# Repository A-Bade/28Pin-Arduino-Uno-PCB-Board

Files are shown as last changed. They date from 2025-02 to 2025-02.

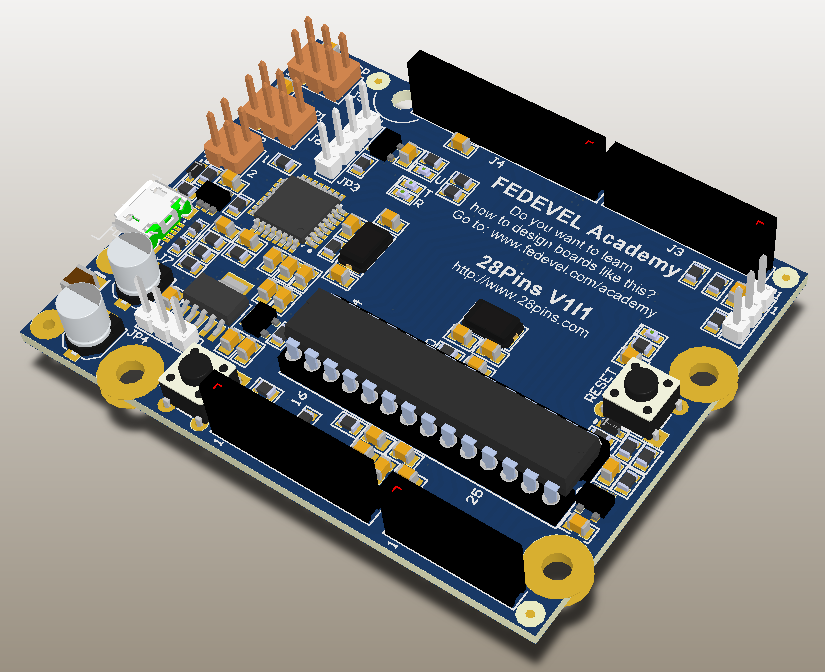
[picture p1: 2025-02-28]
!Design Documentation/Templates/Schematic/28Pins3D.png

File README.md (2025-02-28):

The repo includes:

- Mechanical Drawing (Board dimensions, holes position, ..)
- TOP and BOTTOM Assembly Drawing (Component position with Reference Designator)
- TOP and BOTTOM VIEW (shows board outline, assembly layer, TOP + BOTTOM layers)
- Bill of Materials (grouped by component type)
- Component reference BOM (each component on one line: Designator, Description, Manufacturer 1,
  Manufacturer, Part Number 1, Package / Case, Supplier 1, Supplier Part Number 1)
- Component reference BOM (as above) grouped by component type.
- Pick and Place
- TOP and BOTTOM Layer + TOP and BOTTOM Paste Gerber Files (for stencil - if panel is done in a PCB house, ask them later for the top/bottom layers and paste for the panel)
- PDF 3D Model

!!! BE AWARE !!! If you use a VARIANT were you replace a component by other component,
THIS WILL NOT BE REFLECTED IN ASSEMBLY DRAWING and component will look like not fitted.
This may be a bug in Altium 14.3. Use a TEMP Schematic to generate the ASM DRWG. SAME
FOR PICK & PLACE!!

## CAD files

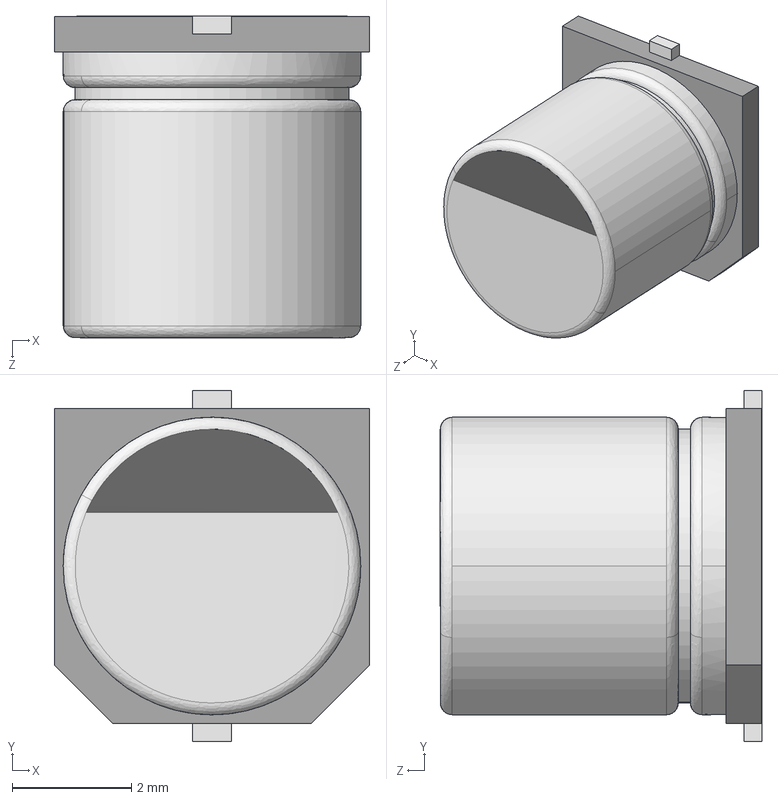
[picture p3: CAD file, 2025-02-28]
!Design Documentation/3D models/capacitor size C.step
5.30 x 5.90 x 5.41 mm

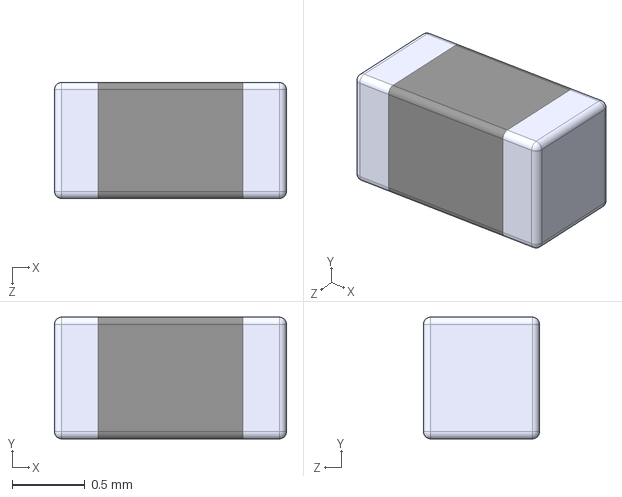
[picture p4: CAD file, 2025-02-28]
!Design Documentation/3D models/R0603.step
1.60 x 0.84 x 0.8 mm

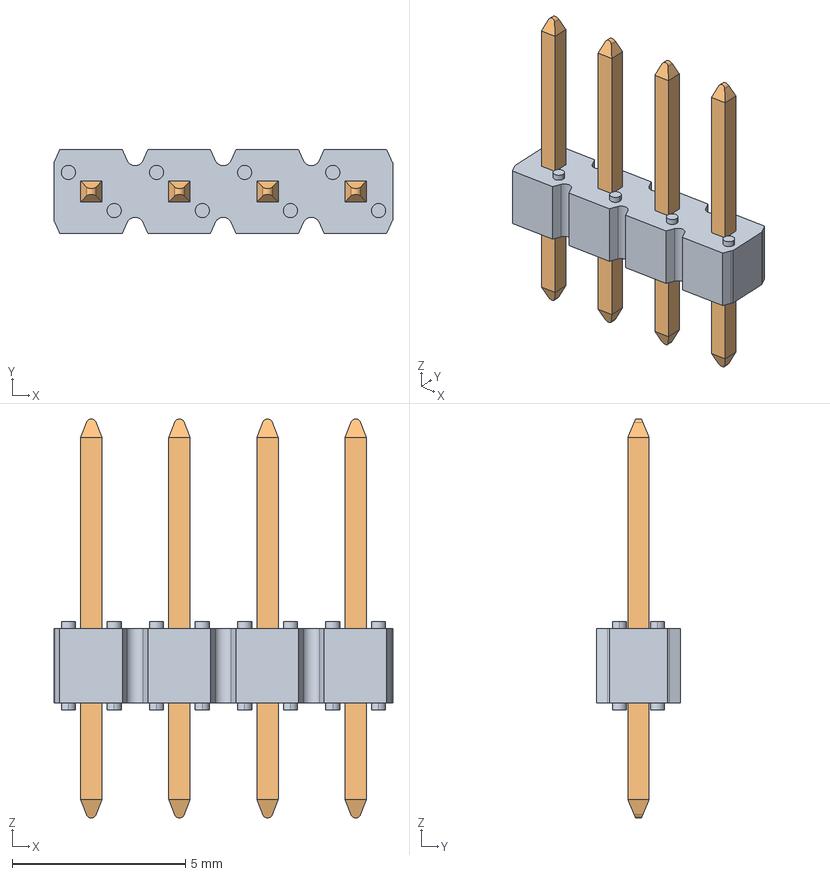
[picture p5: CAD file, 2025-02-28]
!Design Documentation/3D models/HDR_1x4_White.stp
9.76 x 2.41 x 11.5 mm

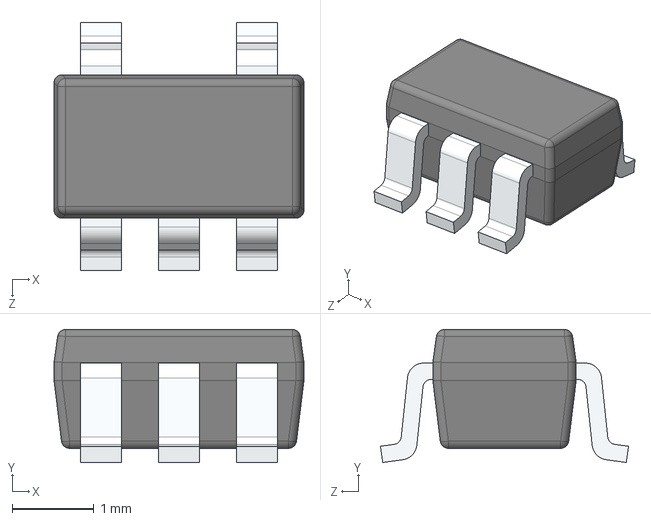
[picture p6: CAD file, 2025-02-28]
!Design Documentation/3D models/DBV.step
3.05 x 1.62 x 3.03 mm

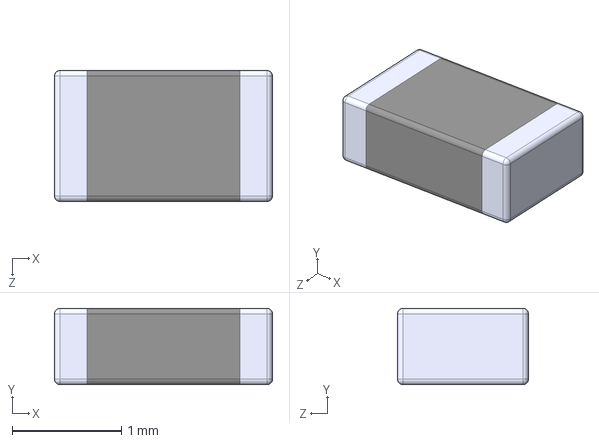
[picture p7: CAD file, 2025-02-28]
!Design Documentation/3D models/RESC2012X70N EIA 0805.step
2.00 x 0.7 x 1.20 mm

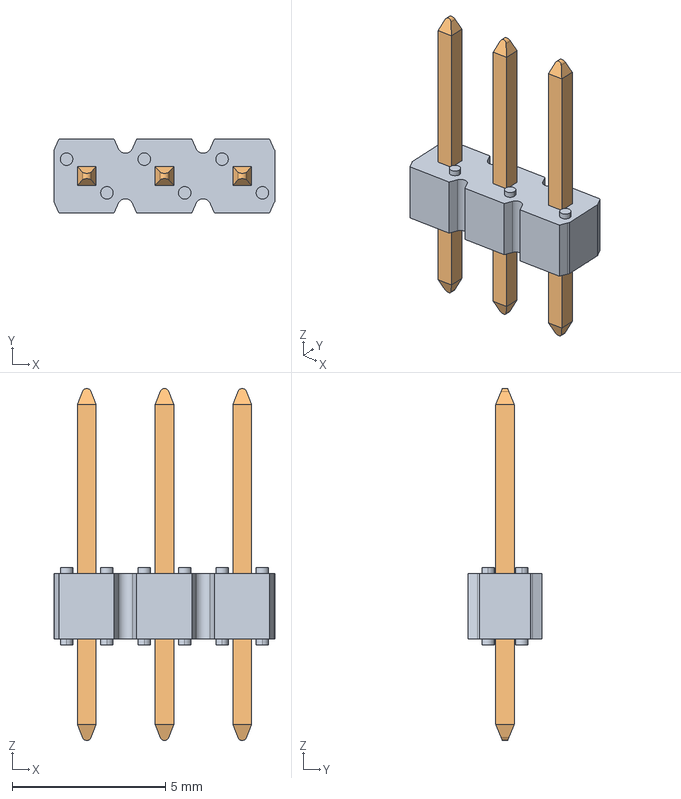
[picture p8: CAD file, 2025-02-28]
!Design Documentation/3D models/HDR_1x3_White.stp
7.22 x 2.41 x 11.5 mm
77310_Y16 x 3

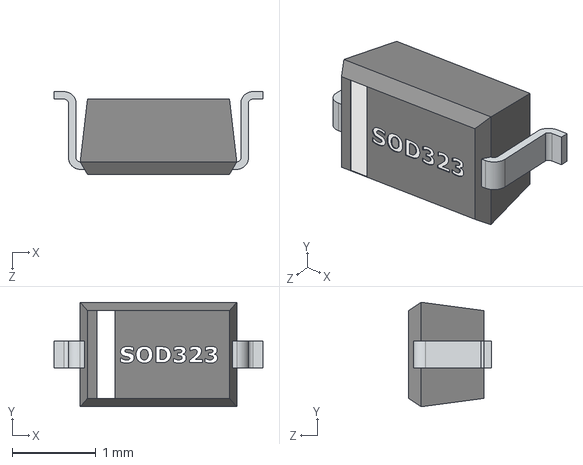
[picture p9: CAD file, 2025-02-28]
!Design Documentation/3D models/SOD323.step
2.50 x 1.25 x 0.99 mm

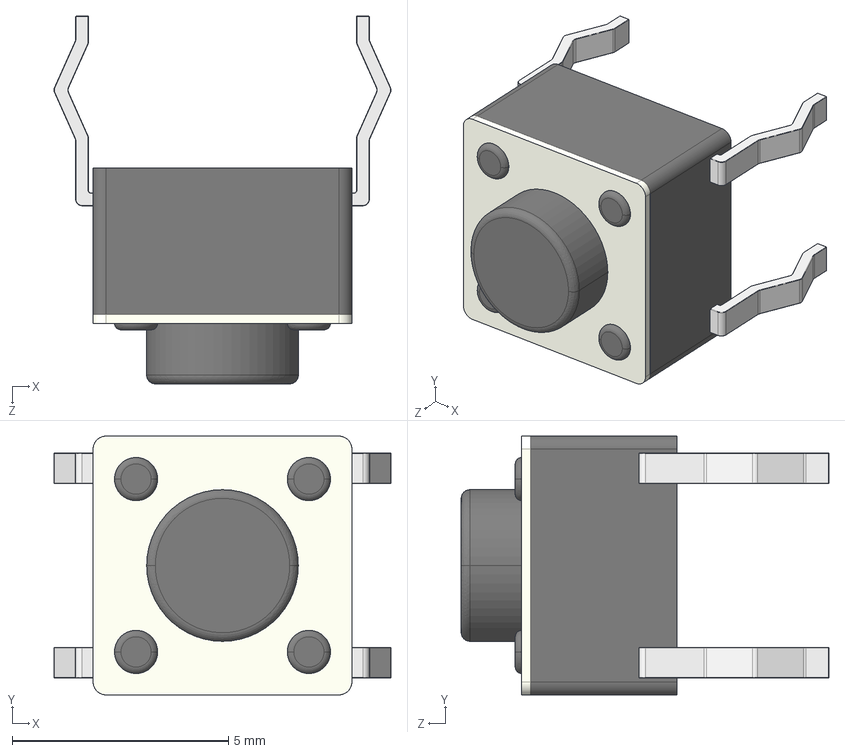
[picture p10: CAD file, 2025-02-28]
!Design Documentation/3D models/FSM4JLH(1825910-5).step
7.80 x 5.99 x 8.51 mm

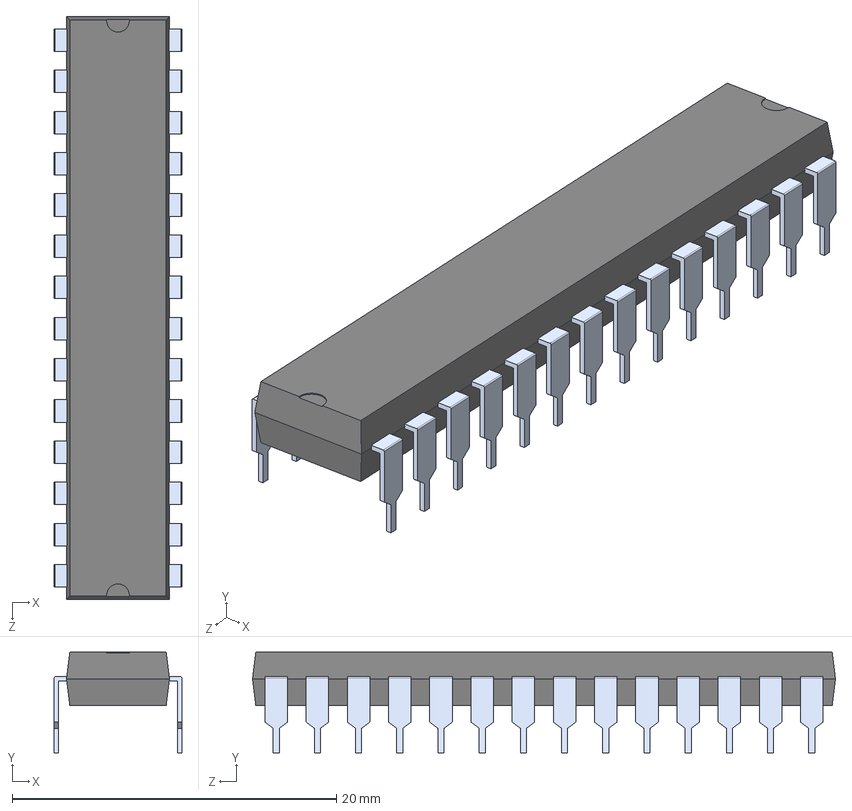
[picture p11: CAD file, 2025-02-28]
!Design Documentation/3D models/28 pin dip.step
7.87 x 6.22 x 35.9 mm

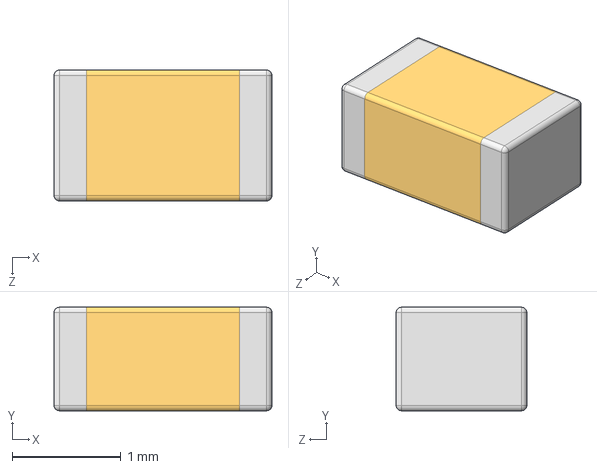
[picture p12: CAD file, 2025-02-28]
!Design Documentation/3D models/CAPC2012X95N EIA 0805.step
2.00 x 0.95 x 1.20 mm

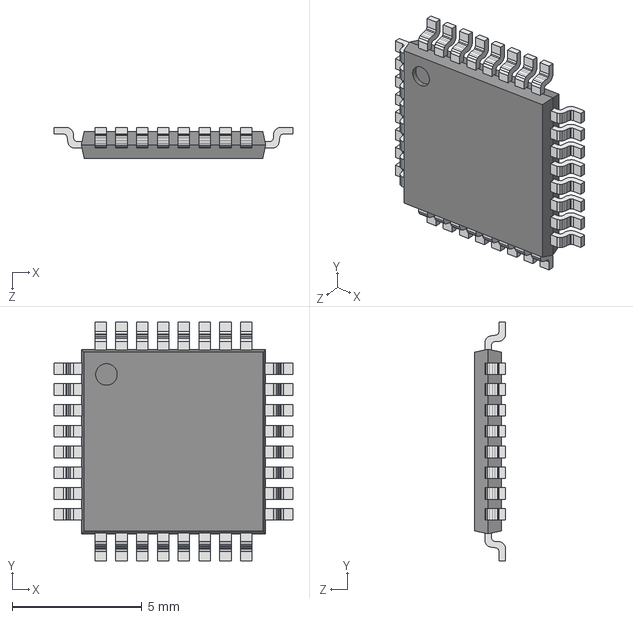
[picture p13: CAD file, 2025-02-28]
!Design Documentation/3D models/tqfp32.step
9.20 x 9.20 x 1.20 mm

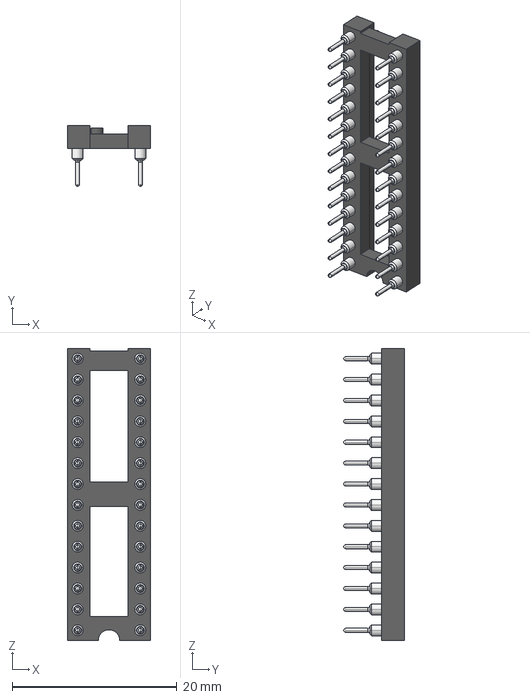
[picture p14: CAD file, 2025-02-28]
!Design Documentation/3D models/dil_socket.stp
10.1 x 7.37 x 35.5 mm

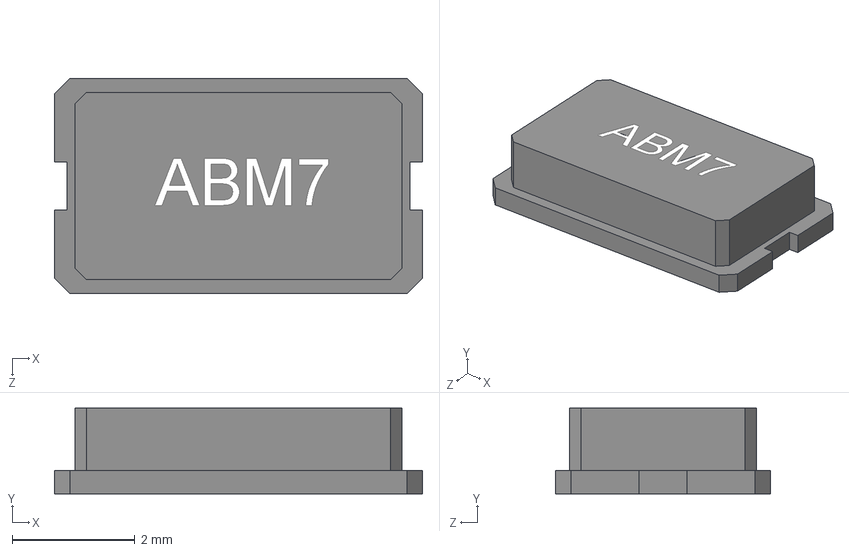
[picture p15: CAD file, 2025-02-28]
!Design Documentation/3D models/ABM7.STEP
5.99 x 1.40 x 3.51 mm

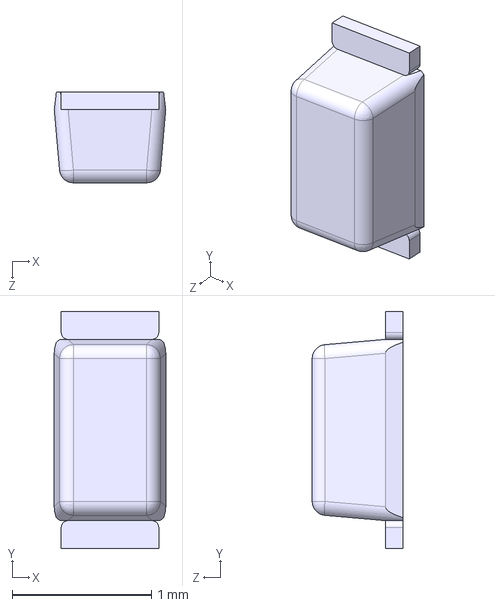
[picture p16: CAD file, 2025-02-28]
!Design Documentation/3D models/LED SMD 0603.step
0.8 x 1.70 x 0.65 mm

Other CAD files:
!Design Documentation/Development Boards/Arduino Uno/Arduino Uno.dxf
!Design Documentation/3D models/m20-7821046_asm.stp
!Design Documentation/3D models/m20-7820842_asm.stp
!Design Documentation/3D models/m20-7820646_asm.stp
!Design Documentation/3D models/961204-6404-XX.stp
!Design Documentation/3D models/961206-6404-XX.stp
!Design Documentation/3D models/TPS73701DCQ.step

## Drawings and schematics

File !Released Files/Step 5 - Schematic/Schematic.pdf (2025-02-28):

# POWER

# POWER PADS

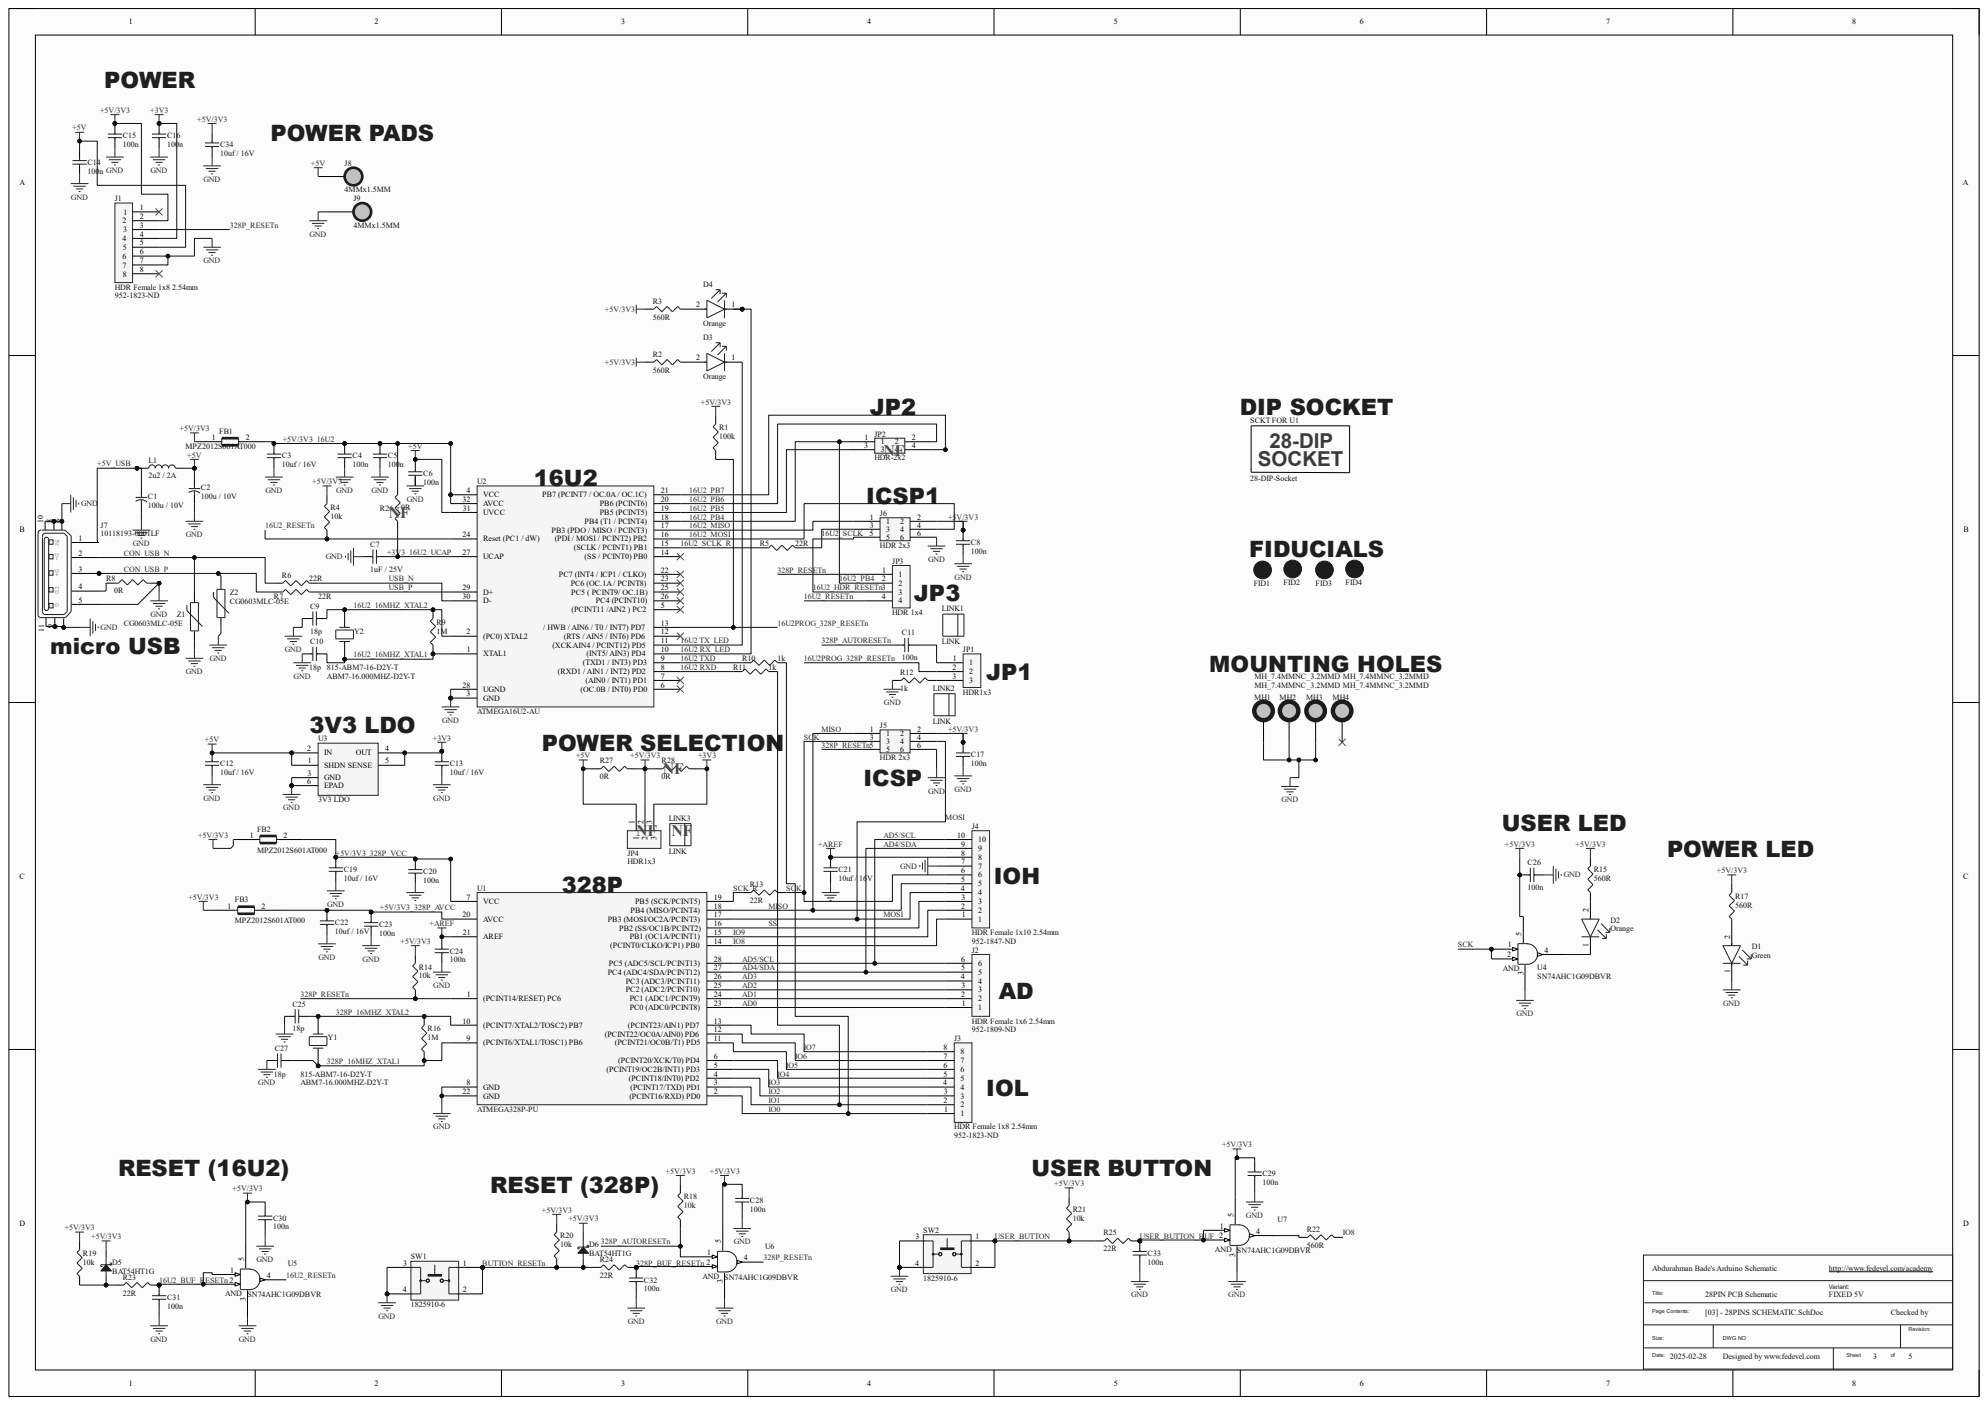
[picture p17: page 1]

Abdurahman Bade's Arduino Schematic

http://www.fedevel.com/academy

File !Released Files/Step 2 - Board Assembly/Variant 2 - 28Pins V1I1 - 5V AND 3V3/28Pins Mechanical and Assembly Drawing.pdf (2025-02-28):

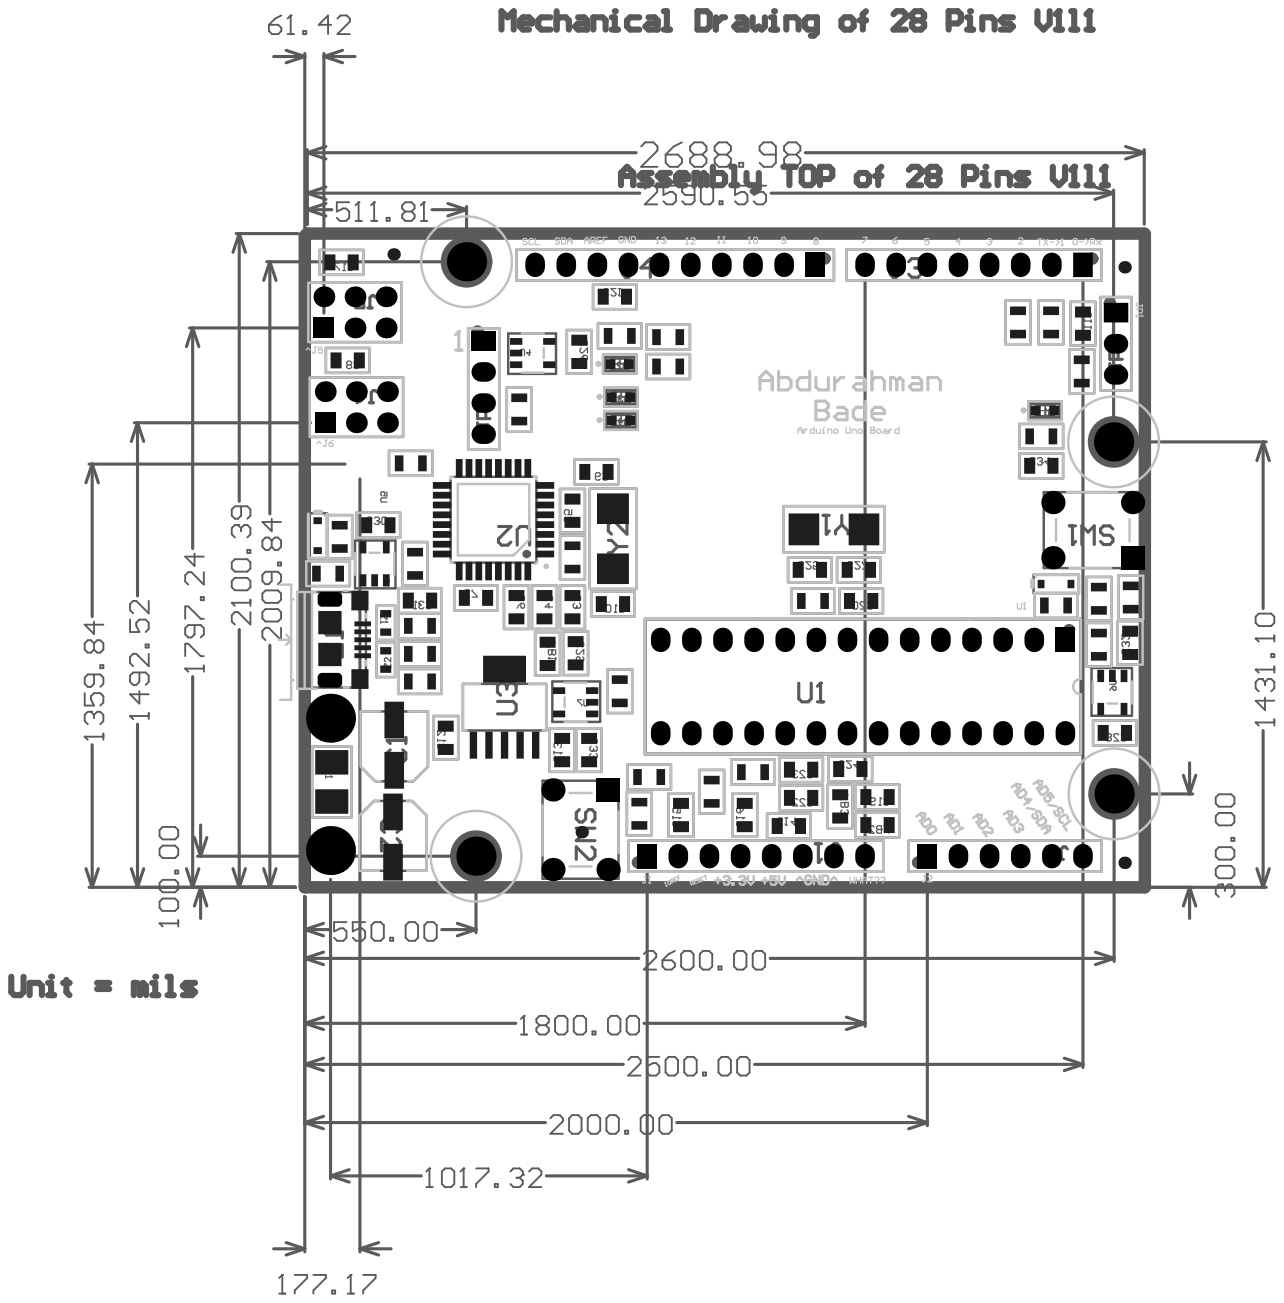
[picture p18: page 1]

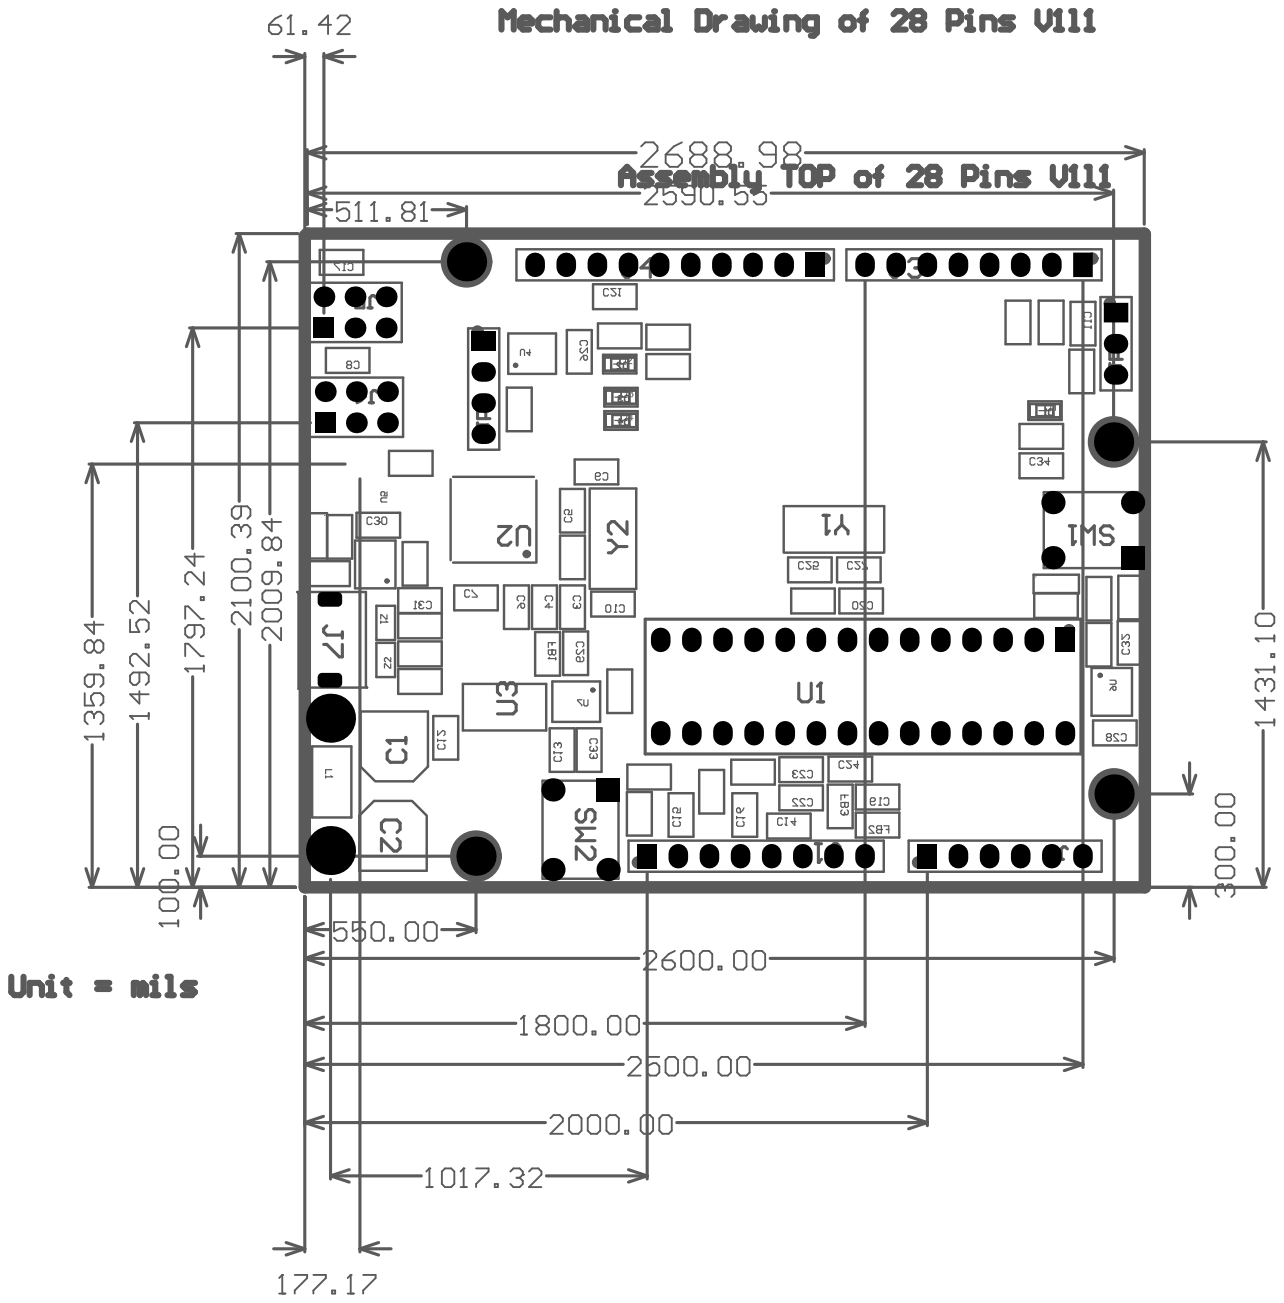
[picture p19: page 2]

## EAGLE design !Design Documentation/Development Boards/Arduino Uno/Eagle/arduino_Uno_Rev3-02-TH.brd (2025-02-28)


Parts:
AD: 6x1F-H8.5; 1X06
C1, C2, C4, C5, C6, C7: 100n; C0603-ROUND
C3, C8: 1u; C0603-ROUND
C9, C11: 22p; C0603-ROUND
D1: M7; SMB
D2, D3: CD1206-S01575; MINIMELF
F1: MF-MSMF050-2 500mA; L1812
FD1, FD2, FD3: FIDUCIALMOUNT; FIDUCIA-MOUNT
GROUND: SJ
ICSP, ICSP1: 3x2 M; 2X03
IOH: 10x1F-H8.5; 1X10
IOL: 8x1F-H8.5; 1X08
JP2: 2x2 M - NM; 2X02
L: YELLOW; CHIP-LED0805
L1: BLM21; 0805
ON: GREEN; CHIP-LED0805
PC1, PC2: 47u; PANASONIC_D
POWER: 8x1F-H8.5; 1X08
R1, R2: 1M; R0603-ROUND
RESET: TS42031-160R-TR-7260; TS42
RESET-EN: SJ
RN1: 10K; CAY16
RN2, RN4: 1K; CAY16
RN3: 22R; CAY16
RX: YELLOW; CHIP-LED0805
T1: FDN340P; SOT-23
TX: YELLOW; CHIP-LED0805
U1: NCP1117ST50T3G; SOT223
U2: LP2985-33DBVR; SOT23-DBV
U3: ATMEGA16U2-MU(R); MLF32
U5: LMV358IDGKR; MSOP08
U$1: DISCLAIMER
X1: POWERSUPPLY_DC21MMX; POWERSUPPLY_DC-21MM
X2: USB-B_TH; PN61729
Y1: 16MHz; QS
Y2: CSTCE16M0V53-R0 16MHZ; RESONATOR
Z1, Z2: CG0603MLC-05E; CT/CN0603
ZU4: ATMEGA328P-PU; DIL28-3

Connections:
5-GND: RESET.5 (5-GND)
+3V3: C3.2, POWER.4, U2.5 (OUT), U5.2 (-IN)
+5V: C1.2, C2.2, C6.2, C7.1, D2.C, D3.C, ICSP.2, ICSP1.2, PC2.+, POWER.2, POWER.5, RN1.3 (1), RN1.5 (2), RN2.2 (1), RN2.3 (1), RN4.3 (1), RN4.4 (1), T1.2 (S), U1.2 (OUT), U1.4 (OUT), U2.1 (IN), U2.3 (ON/!OFF), U3.4 (VCC), U3.32 (AVCC), U5.8 (V+), ZU4.7 (VCC), ZU4.20 (AVCC)
AD0: AD.1, ZU4.23 ((ADC0)PC0))
AD1: AD.2, ZU4.24 ((ADC1)PC1)
AD2: AD.3, ZU4.25 ((ADC2)PC2)
AD3: AD.4, ZU4.26 ((ADC3)PC3)
AD4/SDA: AD.5, IOH.9, ZU4.27 ((ADC4)PC4)
AD5/SCL: AD.6, IOH.10, ZU4.28 ((ADC5)PC5)
AREF: C4.2, IOH.8, ZU4.21 (AREF)
CMP: RN1.1, RN1.2 (1), U5.3 (+IN)
D+: RN3.5 (2), X2.3, Z1.1
D-: RN3.8 (2), X2.2, Z2.1
DTR: C5.1, RN2.4 (1), U3.13 ((CTS/HWB/AIN6/TO/INT7)PD7)
GATE_CMD: T1.3 (G), U5.1 (OUT)
GND: C1.1, C2.1, C3.1, C4.1, C6.1, C7.2, C9.2, C11.2, GROUND.1, ICSP.6, ICSP1.6, IOH.7, L.C, ON.C, PC1.-, PC2.-, POWER.6, POWER.7, RESET.1, RESET.2, RN1.7 (2), RN2.5 (2), U1.1 (GND/ADJ), U2.2 (GND), U3.3 (GND), U3.33 (PAD), U5.4 (V-), X1.1, X1.3, Y2.2, ZU4.8 (GND), ZU4.22 (AGND)
IO0: IOL.1, RN4.2 (1), ZU4.2 ((RXD)PD0)
IO1: IOL.2, RN4.1, ZU4.3 ((TXD)PD1)
IO2: IOL.3, ZU4.4 ((INT0)PD2)
IO3: IOL.4, ZU4.5 ((INT1)PD3)
IO4: IOL.5, ZU4.6 ((T0)PD4)
IO5: IOL.6, ZU4.11 ((T1)PD5)
IO6: IOL.7, ZU4.12 ((AIN0)PD6)
IO7: IOL.8, ZU4.13 ((AIN1)PD7)
IO8: IOH.1, ZU4.14 ((ICP)PB0)
IO9: IOH.2, ZU4.15 ((OC1)PB1)
L13: RN2.8 (2), U5.6 (-IN), U5.7 (OUT)
M8RXD: RN4.7 (2), U3.9 ((TXD1/INT3)PD3)
M8TXD: RN4.8 (2), U3.8 ((RXD1/AIN1/INT2)PD2)
MISO: ICSP.1, IOH.5, ZU4.18 ((MISO)PB4)
MISO2: ICSP1.1, U3.17 ((PD0/MISO/PCINT3)PB3)
MOSI: ICSP.4, IOH.4, ZU4.17 ((MOSI)PB3)
MOSI2: ICSP1.4, U3.16 ((PDI/MOSI/PCINT2)PB2)
unnamed: L.A, RN2.1
unnamed: ON.A, RN4.5 (2), RN4.6 (2)
unnamed: RN2.7 (2), RX.A
unnamed: RN2.6 (2), TX.A
PB4: JP2.1, U3.18 ((T1/PCINT4)PB4)
PB5: JP2.3, U3.19 ((PCINT5)PB5)
PB6: JP2.2, U3.20 ((PCINT6)PB6)
PB7: JP2.4, U3.21 ((PCINT7/OC0A/OC1C)PB7)
PWRIN: D1.A, X1.2
RD+: RN3.4 (1), U3.29 (D+)
RD-: RN3.1, U3.30 (D-)
RESET: C5.2, D2.A, ICSP.5, POWER.3, RESET.3, RESET.4, RESET-EN.1, RESET-EN.2, RN1.4 (1), ZU4.1 (RESET)
RESET2: D3.A, ICSP1.5, RN1.6 (2), U3.24 (RESET(PC1/DW))
RXLED: RX.C, U3.10 ((INT5/AIN3)PD4)
SCK: ICSP.3, IOH.6, U5.5 (+IN), ZU4.19 ((SCK)PB5)
SCK2: ICSP1.3, U3.15 ((SCLK/PCINT1)PB1)
SS: IOH.3, ZU4.16 ((SS)PB2)
TP_VUCAP: C8.1, U3.27 (UCAP)
TXLED: TX.C, U3.11 ((XCK/AIN4/PCINT12)PD5)
UGND: C8.2, GROUND.2, L1.1, U3.28 (UGND), X2.4
USBVCC: F1.1, T1.1 (D), U3.31 (UVCC)
USHIELD: L1.2, X2.P$1, X2.P$2, Z1.2, Z2.2
VIN: D1.C, PC1.+, POWER.8, RN1.8 (2), U1.3 (IN)
XT1: C9.1, R1.1, U3.1 (XTAL1), Y1.2
XT2: C11.1, R1.2, U3.2 (XTAL2(PC0)), Y1.1
XTAL1: R2.1, Y2.3, ZU4.9 (XTAL1)
XTAL2: R2.2, Y2.1, ZU4.10 (XTAL2)
XUSB: F1.2, X2.1

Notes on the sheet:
Arduino(TM) UNO Rev3
USB boot En
SDA
SCL
Use of the ARDUINO name must be compliant with http://www.arduino.cc/en/Main/Policy


Board: 2 copper layers, 68.6 x 53.3 mm, 53 parts (1 on the bottom side), 60 nets.
